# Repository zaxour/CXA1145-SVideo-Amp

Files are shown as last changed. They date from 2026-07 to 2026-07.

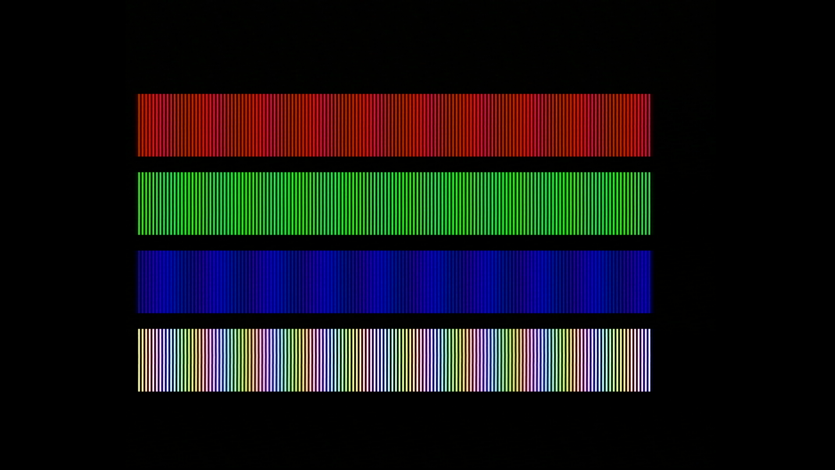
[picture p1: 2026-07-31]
Screenshot 2026-07-30 16-34-33.png

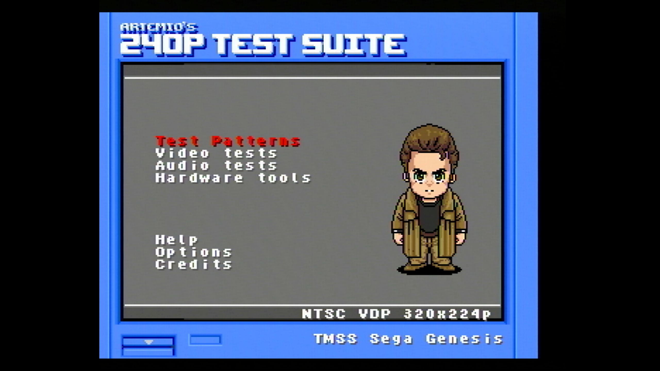
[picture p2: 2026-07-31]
Screenshot 2026-07-30 16-34-21.png

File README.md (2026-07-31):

# CXA1145-SVideo-Amp
S-Video amp for CXA1145 encoders, based on the circuit used in the Amiga CD32. Connect Y (Luma) to pin 16, C (Chroma) to pin 15. 

This has been tested with a Model 1 Sega Genesis using the CXA1145P. Screenshots taken from a Model 1 VA6 Genesis, with RGB bypassed with 4BP, via Retrotink 5X.

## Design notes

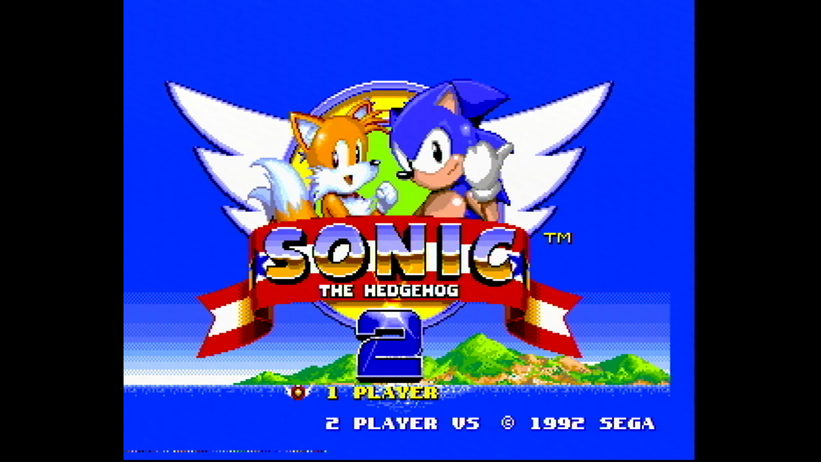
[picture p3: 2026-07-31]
Screenshot 2026-07-30 16-33-01.png

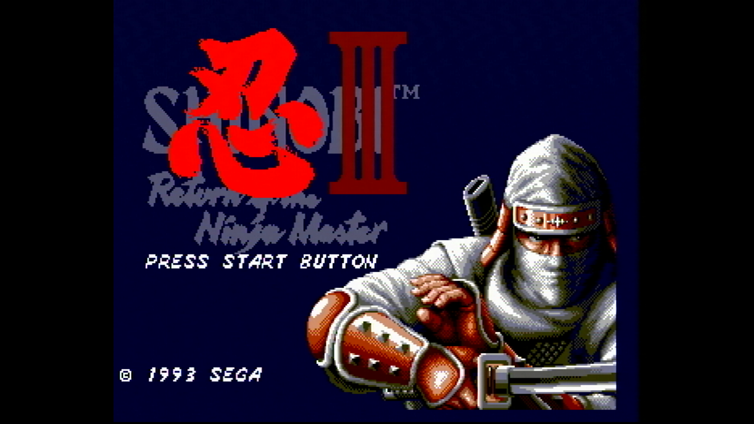
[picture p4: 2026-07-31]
Screenshot 2026-07-30 16-36-08.png

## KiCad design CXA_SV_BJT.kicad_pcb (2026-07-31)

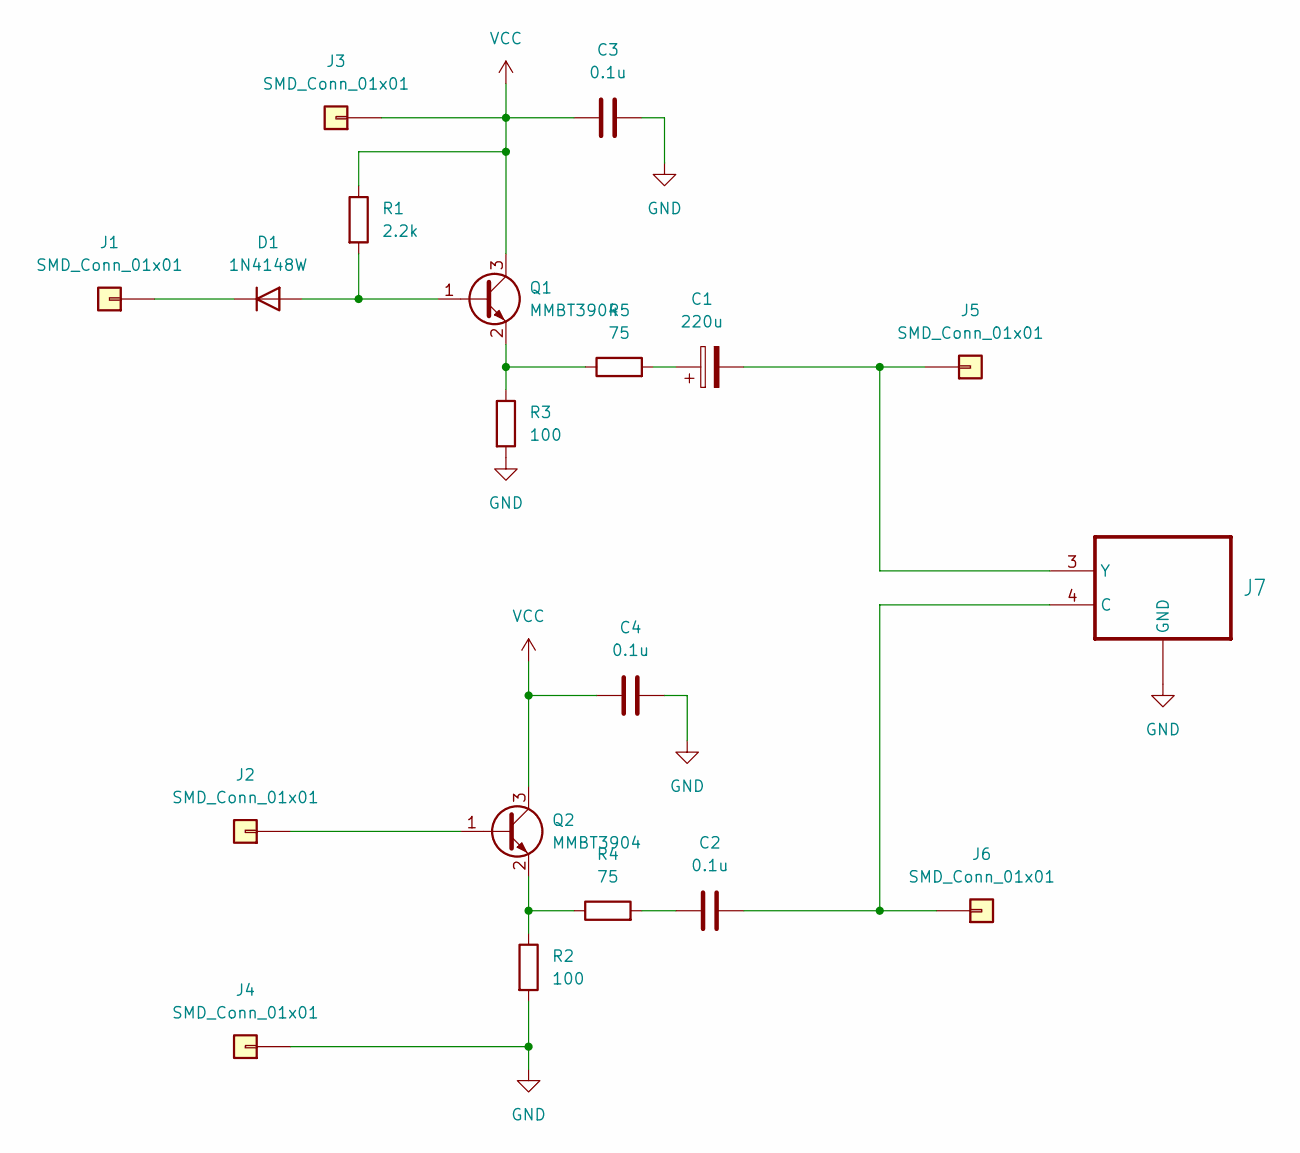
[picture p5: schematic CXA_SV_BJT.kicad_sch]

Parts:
C1: 220u; CP_EIA-3528-15_AVX-H
C2, C3, C4: 0.1u; C_0603_1608Metric
D1: 1N4148W; D_SOD-123
J1, J2, J3, J4, J5, J6: SMD_Conn_01x01; SolderWirePad_1x01_SMD_1x2mm
J7: MD40S_SVid; CUI_MD-40SM
Q1, Q2: MMBT3904; SOT-23
R1: 2.2k; R_0603_1608Metric
R2, R3: 100; R_0603_1608Metric
R4, R5: 75; R_0603_1608Metric

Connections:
GND: C3.2, C4.2, J4.1, J7.1 (GND), J7.2 (GND), J7.S1 (GND), J7.S2 (GND), J7.S3 (GND), R2.2, R3.2
unnamed: C1.1, R5.2
unnamed: C2.1, R4.2
unnamed: D1.2 (A), Q1.1 (B), R1.2
unnamed: D1.1 (K), J1.1
unnamed: J2.1, Q2.1 (B)
unnamed: C1.2, J5.1, J7.3 (Y)
unnamed: C2.2, J6.1, J7.4 (C)
unnamed: Q1.2 (E), R3.1, R5.1
unnamed: Q2.2 (E), R2.1, R4.1
VCC: C3.1, C4.1, J3.1, Q1.3 (C), Q2.3 (C), R1.1

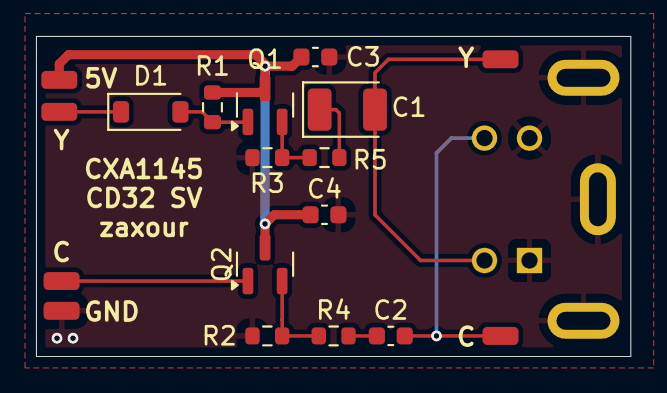
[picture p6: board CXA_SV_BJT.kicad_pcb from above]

Board: 2 copper layers, 33.0 x 17.8 mm, 19 parts (1 on the bottom side), 11 nets.
